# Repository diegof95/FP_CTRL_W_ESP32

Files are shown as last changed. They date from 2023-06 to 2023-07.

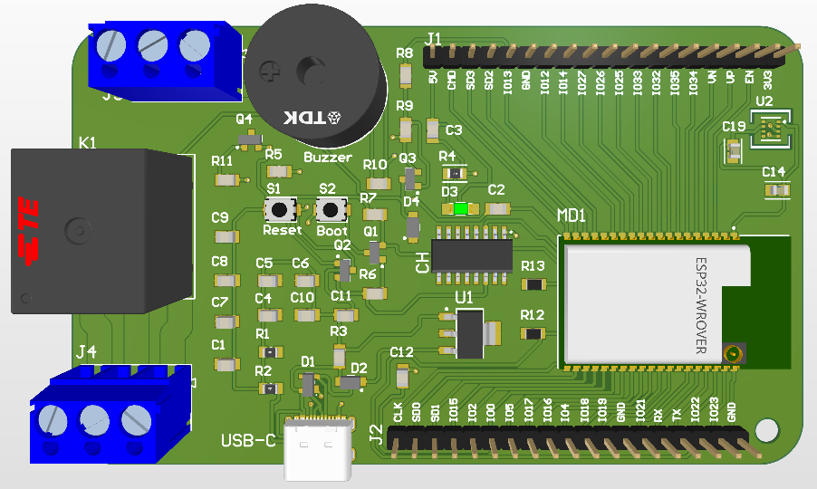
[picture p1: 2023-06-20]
img/frontal_3D.png

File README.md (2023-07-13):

# FP CTRL W ESP32
Proyecto final realizado para el curso de Diseño y Construcción de Dispositivos Electrónicos, perteneciente a la carrera de Ingeniería en Electrónica en Universidad Galileo.  Este proyecto representa mi acercamiento al Internet de las Cosas (IoT), marcando mi primer diseño y ensamblaje de un dispositivo de este tipo en Guatemala.

# ¿Qué podemos hacer?

Desplegar información por medio de un web server o dashboard MQTT por medio de conexión WiFi. Obtener mediciones de temperatura, humedad y presión atmosférica a través del sensor BME280,  controlar cargas AC por medio del relé y una tira led de tipo NeoPixel por medio de la programación y un Buzzer para emitir algún sonido.

# Pinout

### Buzzer
Nombre | GPIO 
--- | --- 
DATA | 12
VDD | 3V3
VSS | GND

### Relé
Nombre | GPIO 
--- | --- 
DATA | 13
VDD | 5V
VSS | GND

### Tira led - WS2812B
Nombre | GPIO 
--- | --- 
DATA | 14
VDD | 5V
VSS | GND

### Sensor de temperatura, humedad y presión - Comunicación I2C (Pendiente de funcionamiento)
BME280 | ESP32
--- | ---
SDI 3 | SDA 21
SCK 4 |  SCL 22 

# Licencia

Hardware License: CERN Open Hardware License Version 2

Software License: GNU General Public License Version 3.0

Documentation License: CC BY 4.0 International



# Contacto e información adicional

Autor: Diego Iboy (diego.iboy@galileo.edu)

Vídeo del funcionamiento: https://youtu.be/rUuOkdmCc4Q

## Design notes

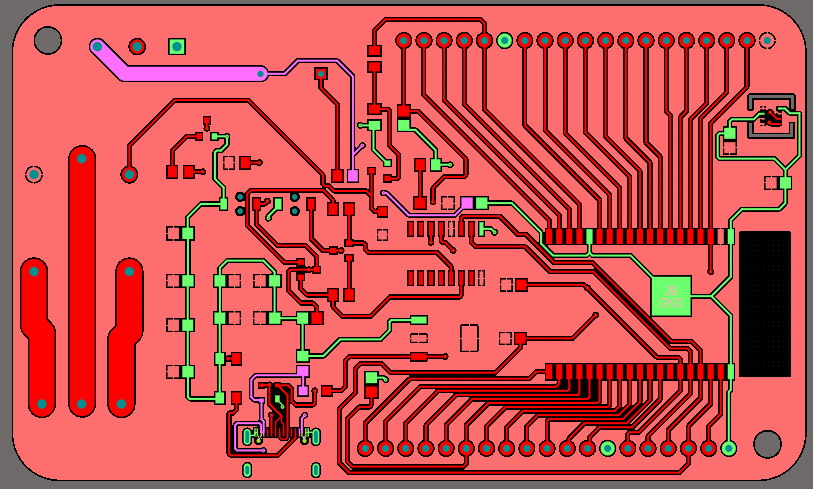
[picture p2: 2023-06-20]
img/font layer.png

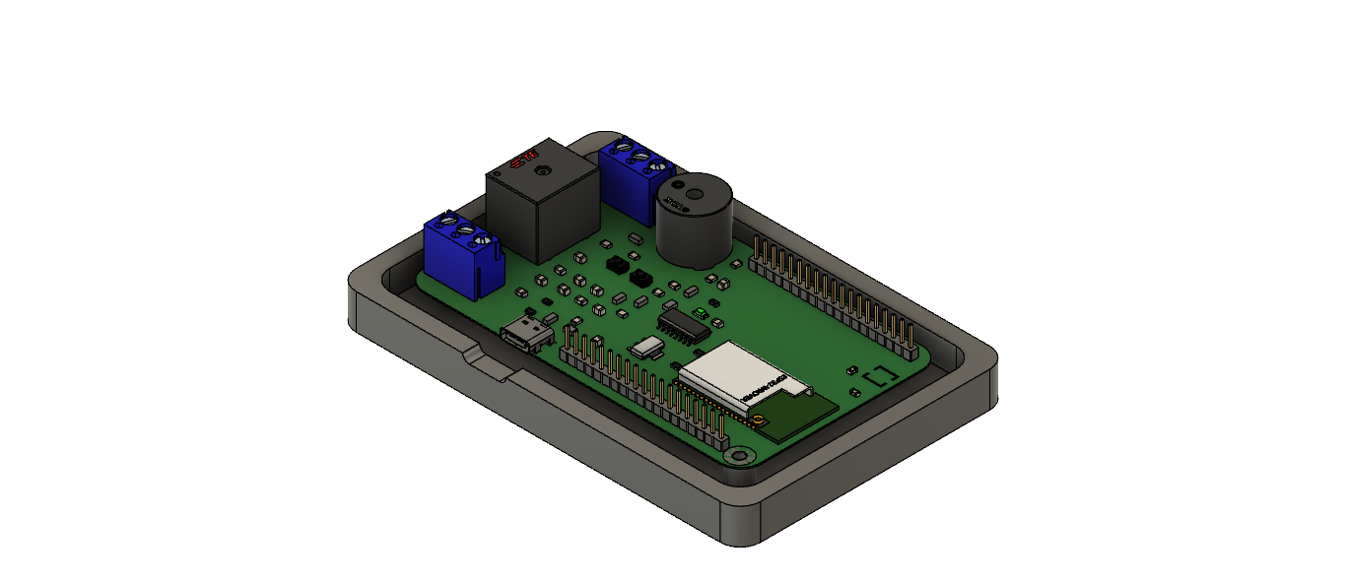
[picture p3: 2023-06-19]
img/Vista 3D.png

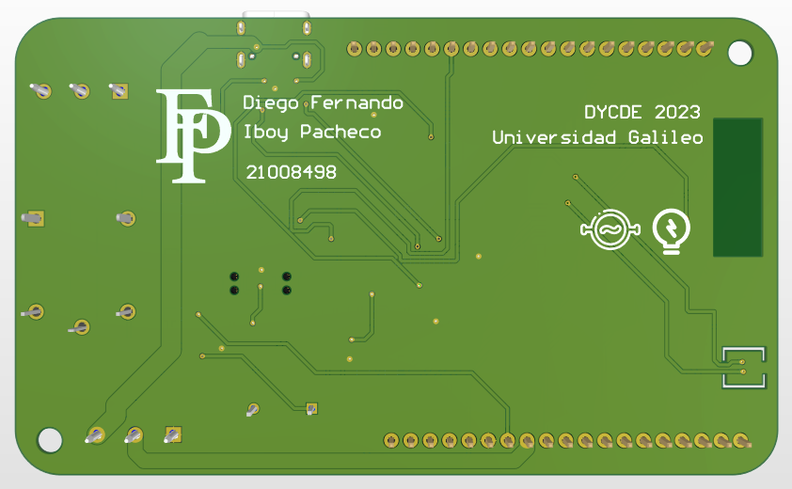
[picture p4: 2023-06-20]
img/trasera_3D.png

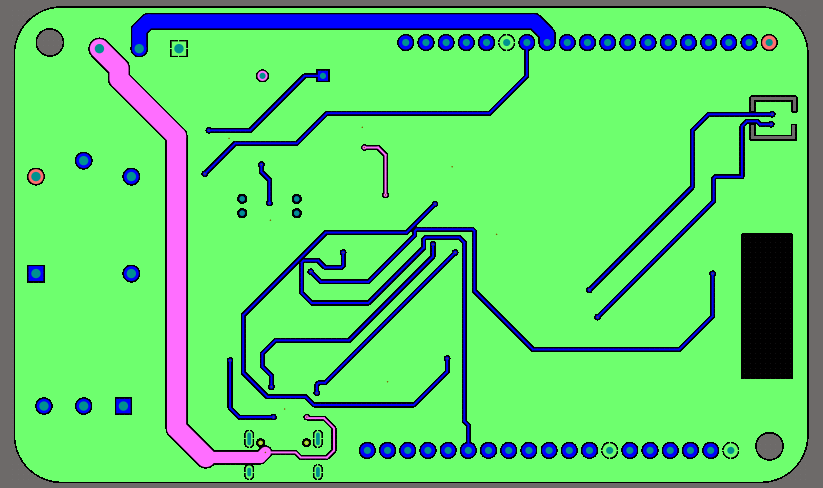
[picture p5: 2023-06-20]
img/bottom layer.png

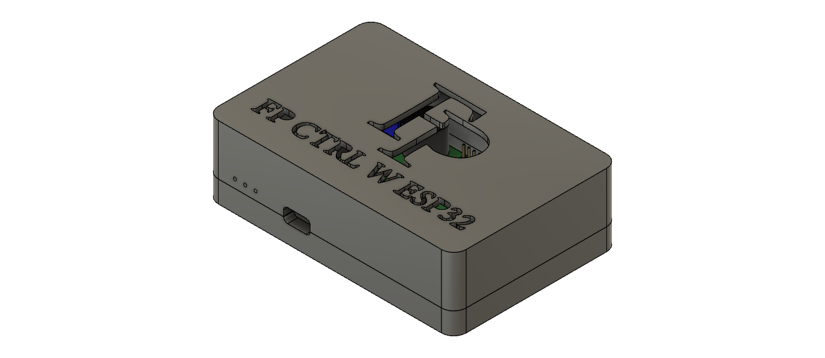
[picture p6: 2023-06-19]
img/vista frontal.png

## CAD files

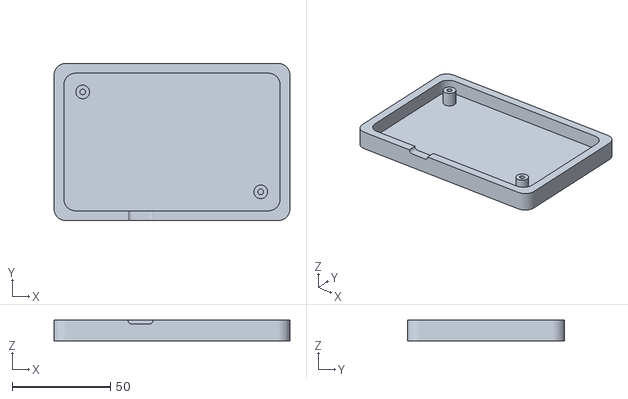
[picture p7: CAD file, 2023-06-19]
hardware/case/Cara trasera.stl
120.0 x 80.0 x 10.5

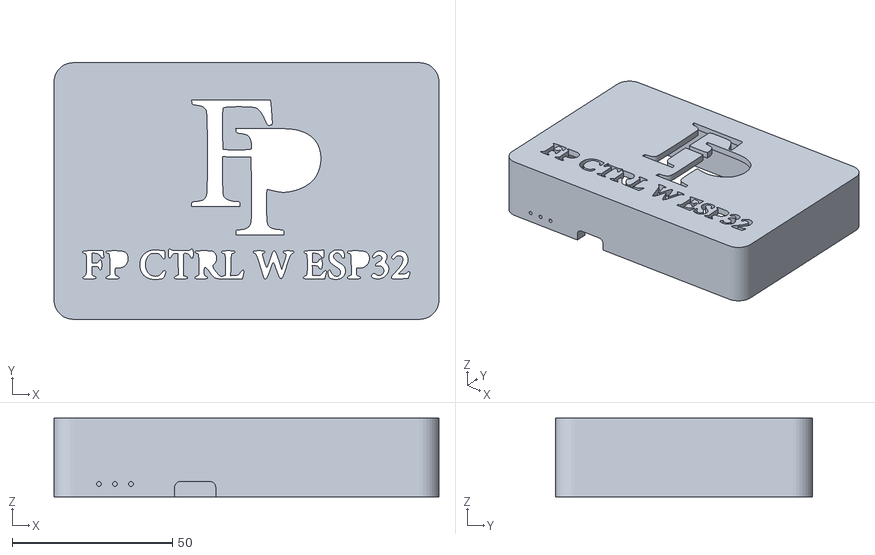
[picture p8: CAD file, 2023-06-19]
hardware/case/Cara frontal.stl
120.0 x 80.0 x 24.5

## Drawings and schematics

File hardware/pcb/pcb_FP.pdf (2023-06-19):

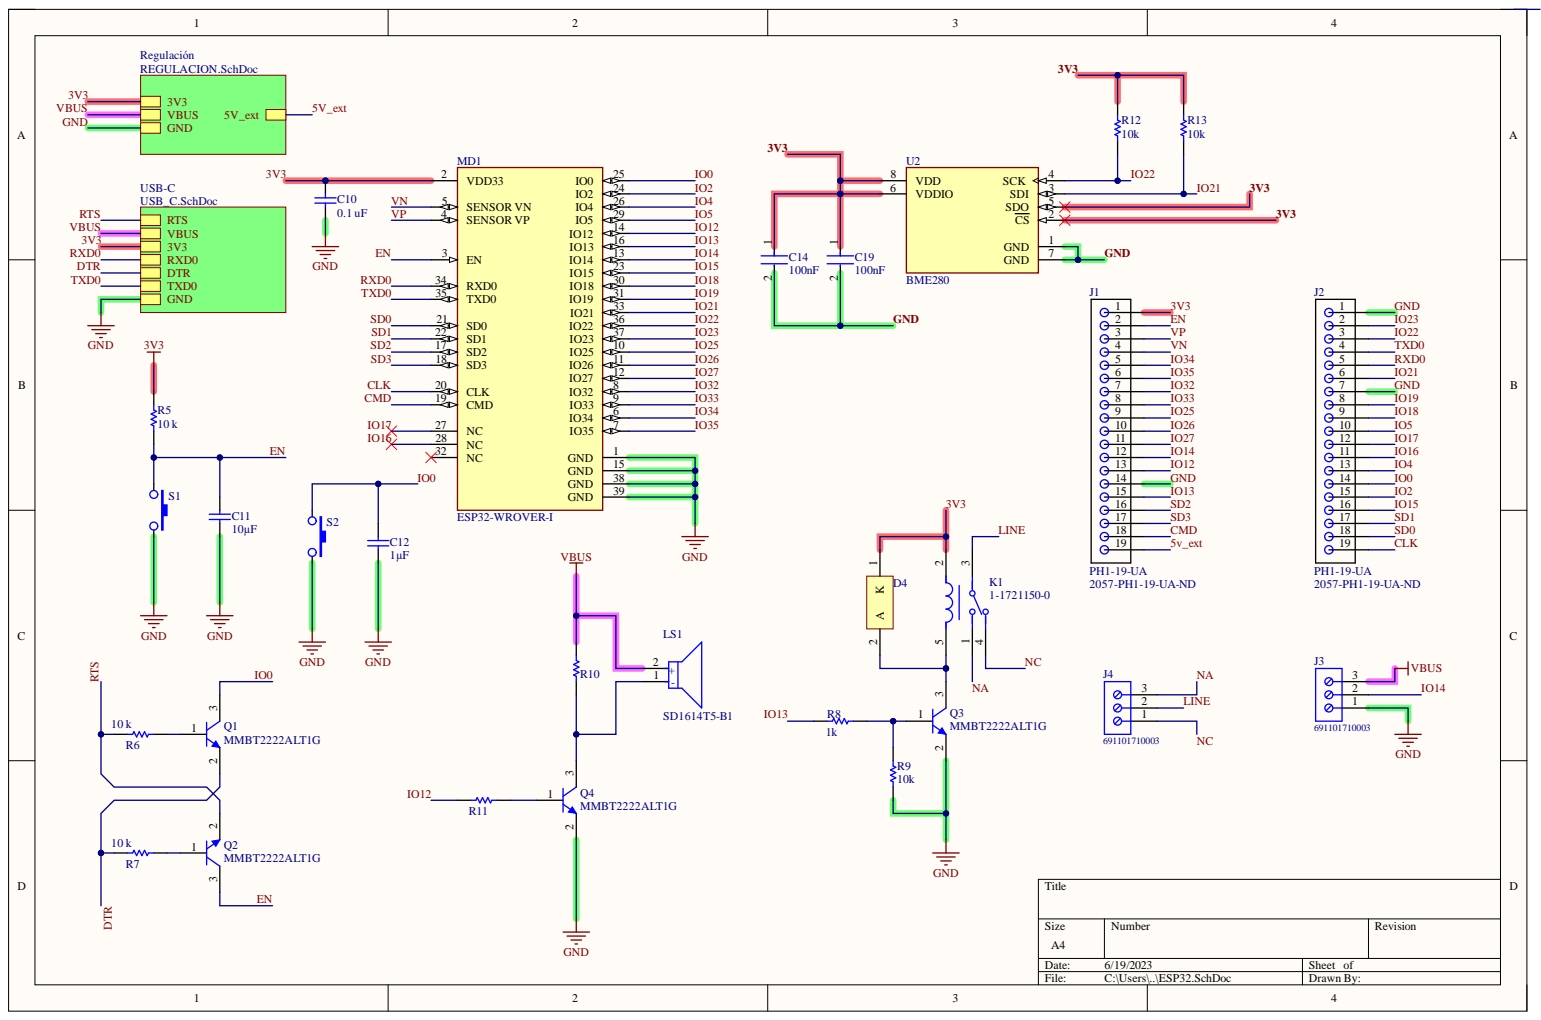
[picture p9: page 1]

1 5
3 8
3 9

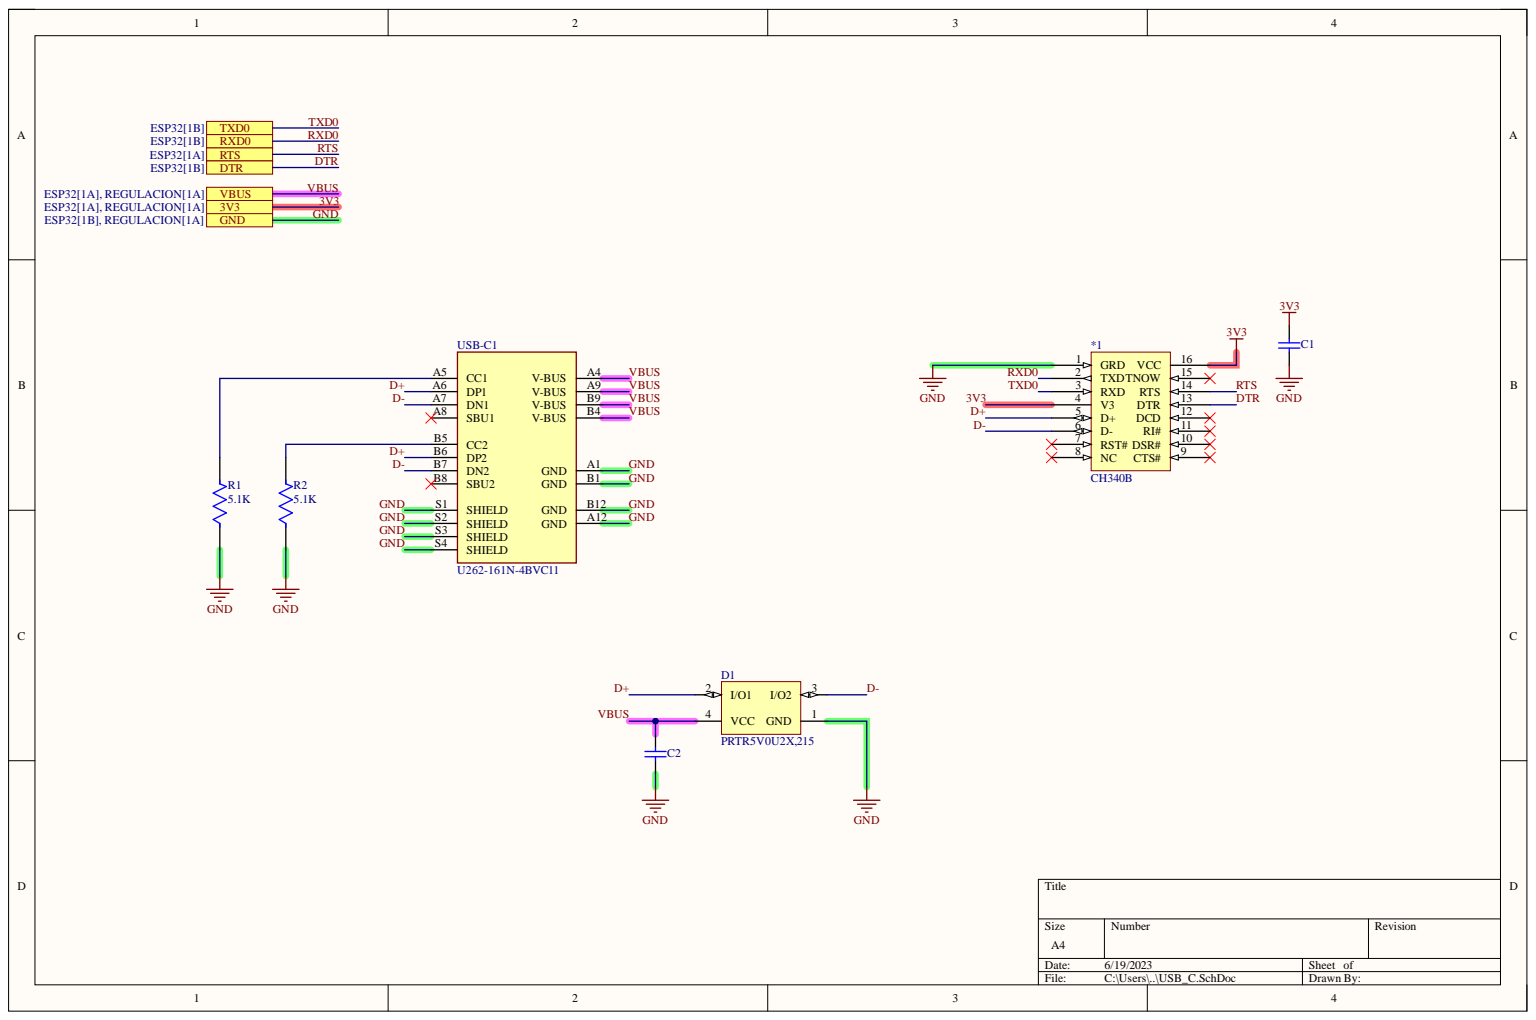
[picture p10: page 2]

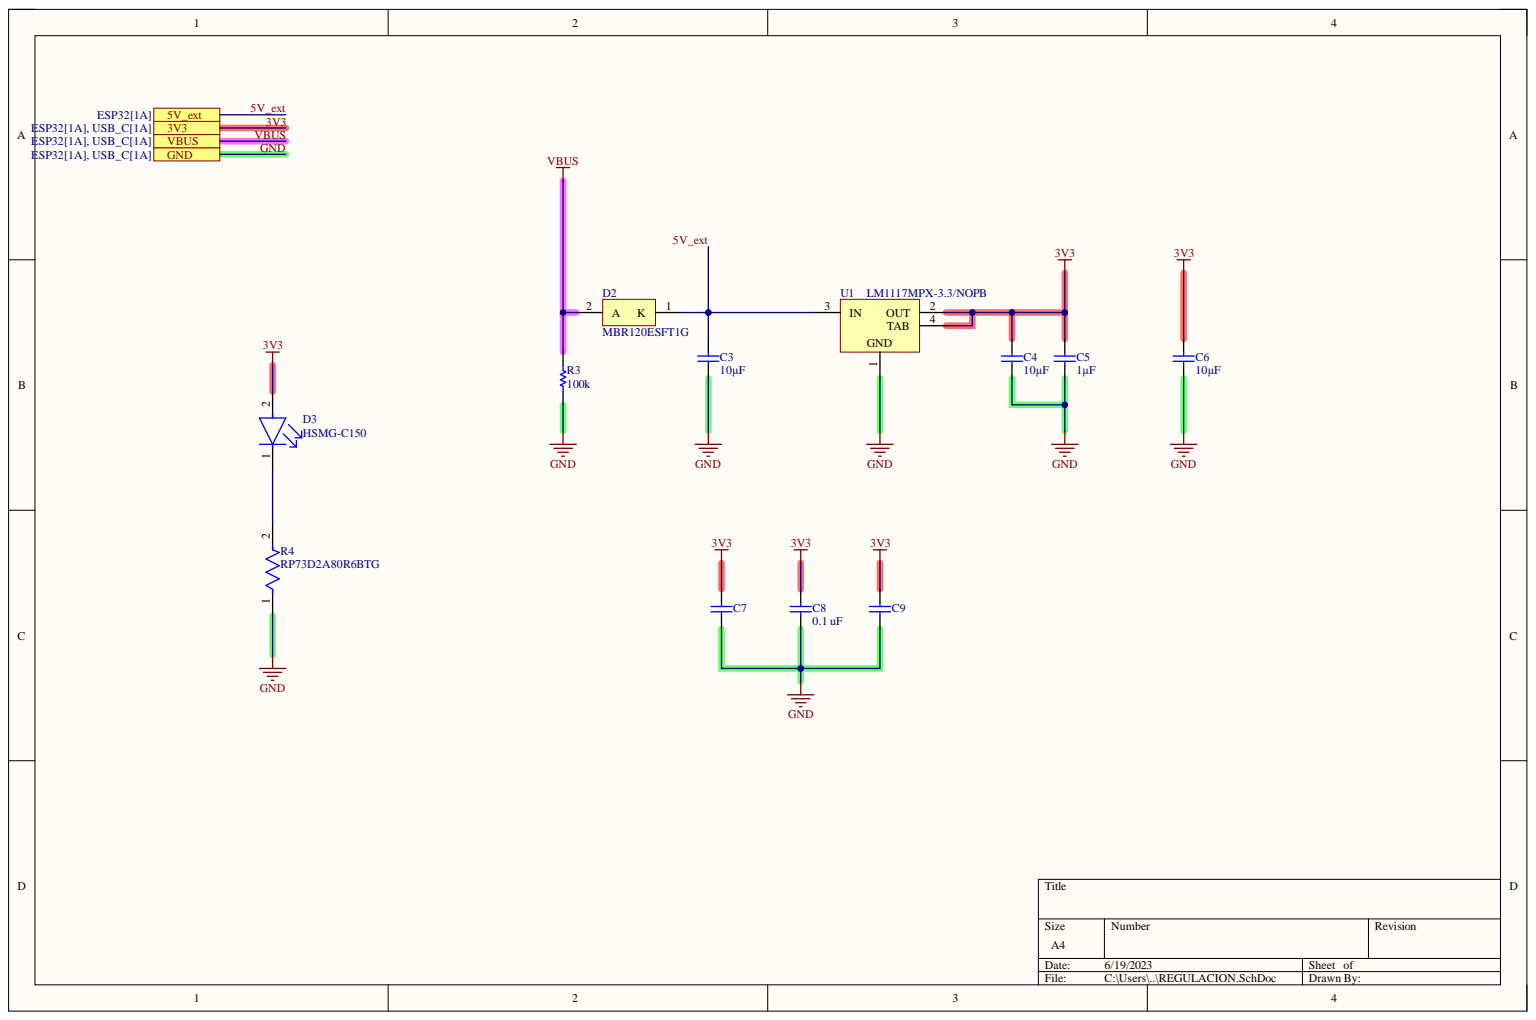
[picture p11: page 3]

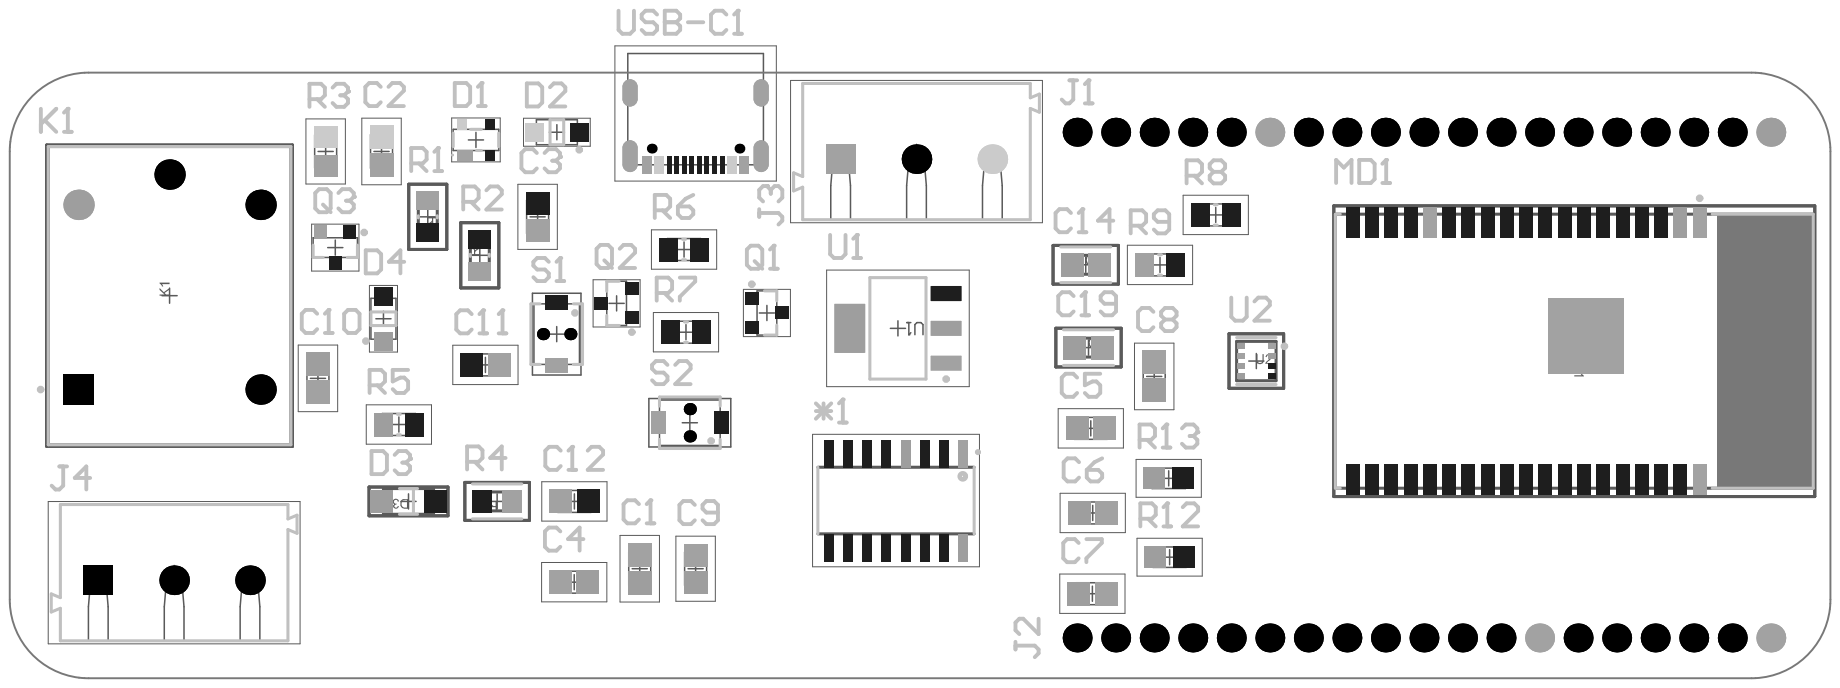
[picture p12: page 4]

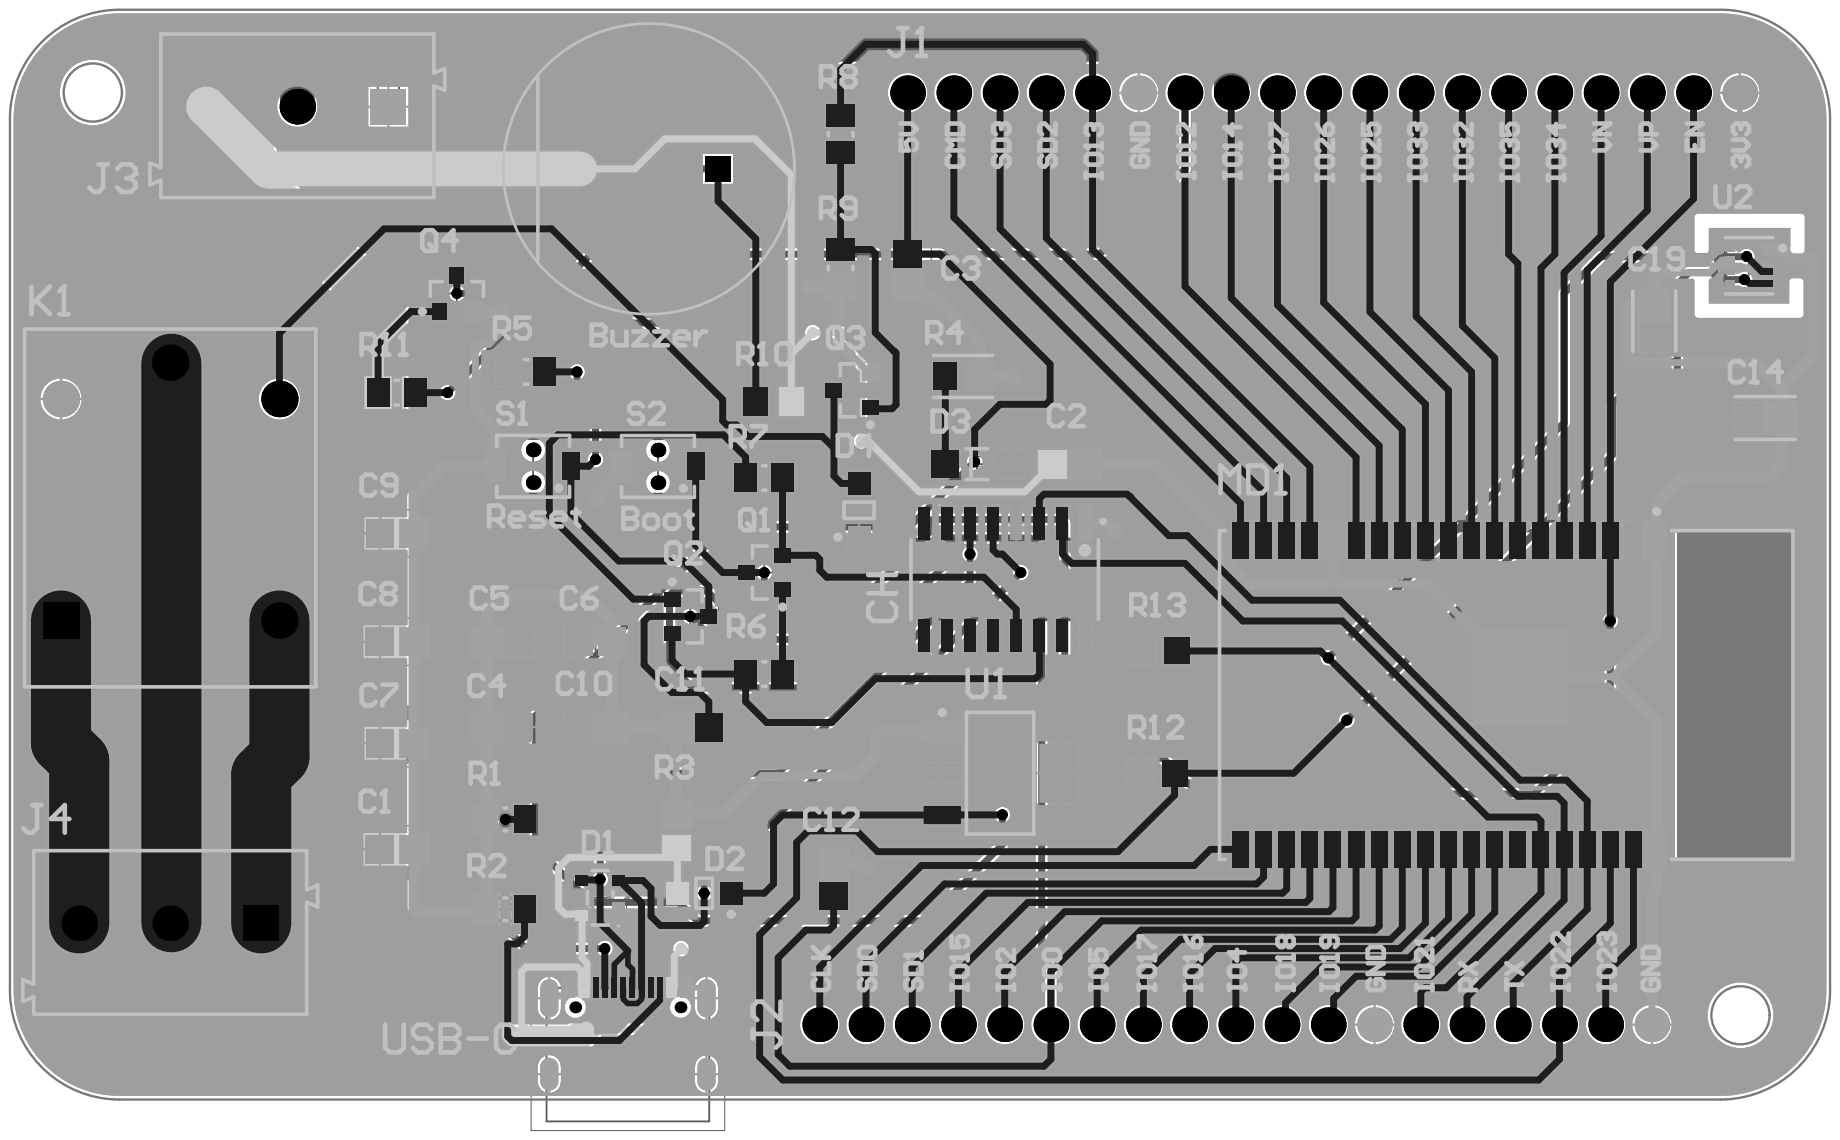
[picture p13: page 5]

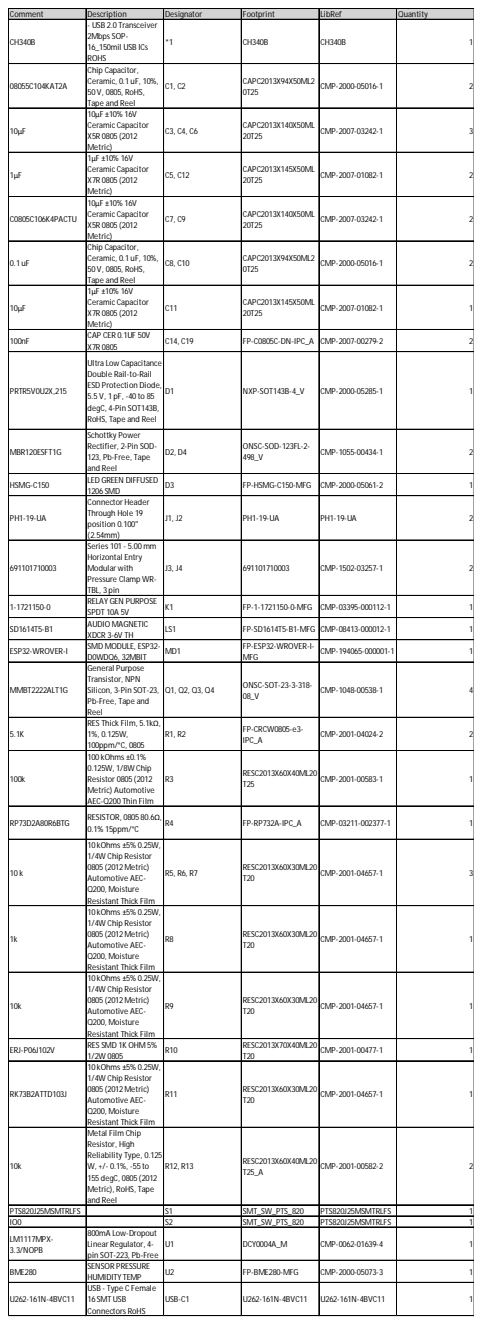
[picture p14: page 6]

Comment | Description | Designator | Footprint | LibRef | Quantity
CH340B | - USB 2.0 Transceiver 2Mbps SOP-16_150mil USB ICs ROHS | *1 | CH340B | CH340B | | 1

08055C104KAT2A | Chip Capacitor, Ceramic, 0.1 uF, 10%, 50 V, 0805, RoHS, Tape and Reel | C1, C2 | CAPC2013X94X50ML2 0T25 | CMP-2000-05016-1 | | 2

10µF | 10µF ±10% 16V Ceramic Capacitor X5R 0805 (2012 Metric) | C3, C4, C6 | CAPC2013X140X50ML 20T25 | CMP-2007-03242-1 | | 3

1µF | 1µF ±10% 16V Ceramic Capacitor X7R 0805 (2012 Metric) | C5, C12 | CAPC2013X145X50ML 20T25 | CMP-2007-01082-1 | | 2

C0805C106K4PACTU | 10µF ±10% 16V Ceramic Capacitor X5R 0805 (2012 Metric) | C7, C9 | CAPC2013X140X50ML 20T25 | CMP-2007-03242-1 | | 2

0.1 uF | Chip Capacitor, Ceramic, 0.1 uF, 10%, 50 V, 0805, RoHS, Tape and Reel | C8, C10 | CAPC2013X94X50ML2 0T25 | CMP-2000-05016-1 | | 2

10µF | 1µF ±10% 16V Ceramic Capacitor X7R 0805 (2012 Metric) | C11 | CAPC2013X145X50ML 20T25 | CMP-2007-01082-1 | | 1

100nF | CAP CER 0.1UF 50V X7R 0805 | C14, C19 | FP-C0805C-DN-IPC_A | CMP-2007-00279-2 | | 2

PRTR5V0U2X,215 | Ultra Low Capacitance Double Rail-to-Rail ESD Protection Diode, 5.5 V, 1 pF, -40 to 85 degC, 4-Pin SOT143B, RoHS, Tape and Reel | D1 | NXP-SOT143B-4_V | CMP-2000-05285-1 | | 1

MBR120ESFT1G | Schottky Power Rectifier, 2-Pin SOD-123, Pb-Free, Tape and Reel | D2, D4 | ONSC-SOD-123FL-2-498_V | CMP-1055-00434-1 | | 2

HSMG-C150 | LED GREEN DIFFUSED 1206 SMD | D3 | FP-HSMG-C150-MFG | CMP-2000-05061-2 | | 1

PH1-19-UA | Connector Header Through Hole 19 position 0.100" (2.54mm) | J1, J2 | PH1-19-UA | PH1-19-UA | | 2

691101710003 | Series 101 - 5.00mm Horizontal Entry Modular with Pressure Clamp WR-TBL, 3 pin | J3, J4 | 691101710003 | CMP-1502-03257-1 | | 2

1-1721150-0 | RELAY GEN PURPOSE SPDT 10A 5V | K1 | FP-1-1721150-0-MFG | CMP-03395-000112-1 | | 1

SD1614T5-B1 | AUDIO MAGNETIC XDCR 3-6V TH | LS1 | FP-SD1614T5-B1-MFG | CMP-08413-000012-1 | | 1

ESP32-WROVER-I | SMD MODULE, ESP32-D0WDQ6, 32MBIT | MD1 | FP-ESP32-WROVER-I-MFG | CMP-194065-000001-1 | | 1

MMBT2222ALT1G | General Purpose Transistor, NPN Silicon, 3-Pin SOT-23, Pb-Free, Tape and Reel | Q1, Q2, Q3, Q4 | ONSC-SOT-23-3-318-08_V | CMP-1048-00538-1 | | 4

5.1K | RES Thick Film, 5.1kΩ, 1%, 0.125W, 100ppm/°C, 0805 | R1, R2 | FP-CRCW0805-e3-IPC_A | CMP-2001-04024-2 | | 2

100k | 100 kOhms ±0.1% 0.125W, 1/8W Chip Resistor 0805 (2012 Metric) Automotive AEC-Q200 Thin Film | R3 | RESC2013X60X40ML20 T25 | CMP-2001-00583-1 | | 1

RP73D2A80R6BTG | RESISTOR, 0805 80.6Ω, 0.1% 15ppm/°C | R4 | FP-RP732A-IPC_A | CMP-03211-002377-1 | | 1

10 k | 10 kOhms ±5% 0.25W, 1/4W Chip Resistor 0805 (2012 Metric) Automotive AEC-Q200, Moisture Resistant Thick Film | R5, R6, R7 | RESC2013X60X30ML20 T20 | CMP-2001-04657-1 | | 3

1k | 10 kOhms ±5% 0.25W, 1/4W Chip Resistor 0805 (2012 Metric) Automotive AEC-Q200, Moisture Resistant Thick Film | R8 | RESC2013X60X30ML20 T20 | CMP-2001-04657-1 | | 1

10k | 10 kOhms ±5% 0.25W, 1/4W Chip Resistor 0805 (2012 Metric) Automotive AEC-Q200, Moisture Resistant Thick Film | R9 | RESC2013X60X30ML20 T20 | CMP-2001-04657-1 | | 1

ERJ-P06J102V | RES SMD 1K OHM 5% 1/2W 0805 | R10 | RESC2013X70X40ML20 T20 | CMP-2001-00477-1 | | 1

RK73B2ATTD103J | 10 kOhms ±5% 0.25W, 1/4W Chip Resistor 0805 (2012 Metric) Automotive AEC-Q200, Moisture Resistant Thick Film | R11 | RESC2013X60X30ML20 T20 | CMP-2001-04657-1 | | 1

10k | Metal Film Chip Resistor, High Reliability Type, 0.125 W, +/- 0.1%, -55 to 155 degC, 0805 (2012 Metric), RoHS, Tape and Reel | R12, R13 | RESC2013X60X40ML20 T25_A | CMP-2001-00582-2 | | 2

PTS820J25MSMTRLFS | | S1 | SMT_SW_PTS_820 | PTS820J25MSMTRLFS | | 1
IO0 | | S2 | SMT_SW_PTS_820 | PTS820J25MSMTRLFS | | 1
LM1117MPX-3.3/NOPB | 800mA Low-Dropout Linear Regulator, 4-pin SOT-223, Pb-Free | U1 | DCY0004A_M | CMP-0062-01639-4 | | 1

BME280 | SENSOR PRESSURE HUMIDITY TEMP | U2 | FP-BME280-MFG | CMP-2000-05073-3 | | 1

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
